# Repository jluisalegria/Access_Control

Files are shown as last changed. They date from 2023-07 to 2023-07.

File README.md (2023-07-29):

# Access control with RFID reader. IoT Contest 2023 RT-Thread.

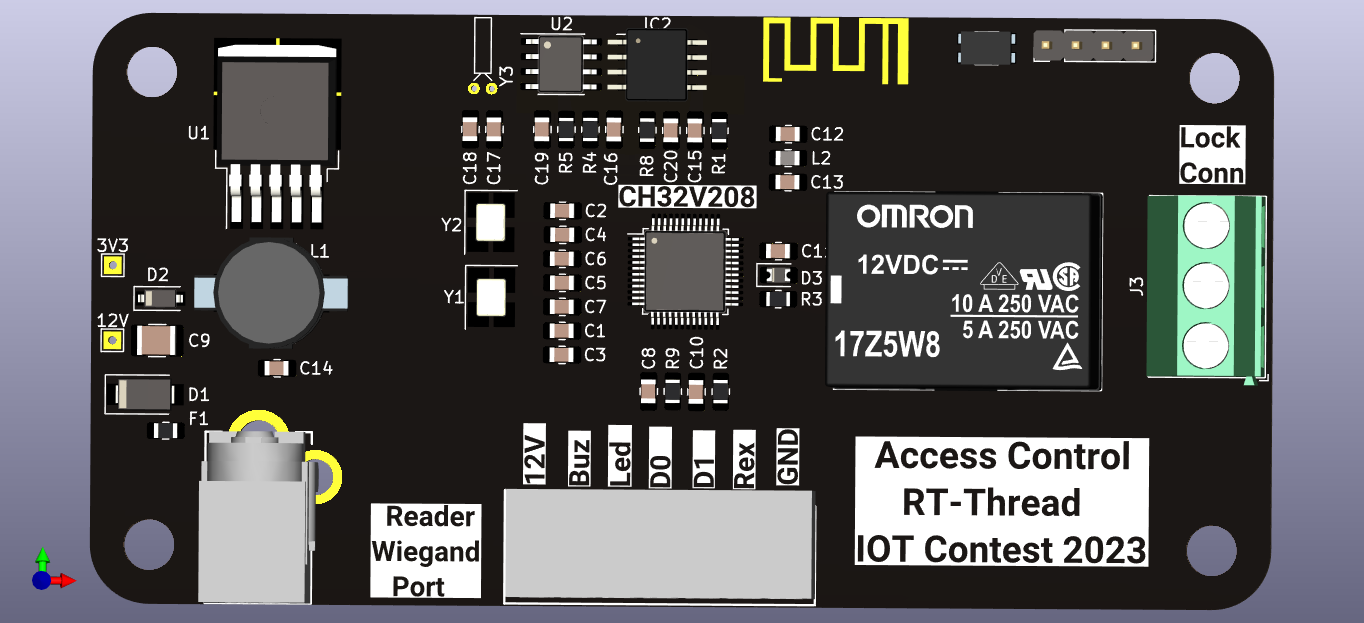
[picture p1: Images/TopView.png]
TOP

# Introduction
I made this project to participate in the IoT contest from RT-Thread.  
[RT-Thread](https://www.rt-thread.io/ "RT-Thread") is a tiny and elegant IoT Operating System.

RT-Thread Features
- Designed for resource-constrained devices, the minimum kernel requires only 1.2KB of RAM and 3 KB of Flash.
- Has rich components and a prosperous and fast growing package ecosystem.
- Elegant code style, easy to use, read and master.
- High Scalability. RT-Thread has high-quality scalable software architecture, loose coupling, modularity, is easy to tailor and expand.
- Supports high-performance applications.
- Supports cross-platform and a wide range of chips.

# Brief
On this project I create my own access control board with RFID wiegand 26 compatible.
There are too many comercial devices, but always the protocolo and software are close, and you have to use the software that the vendor have.
In my case I want to create this access control with the finality to add more functionalityes, for example, automatization of lights AAC control, proyectors, etc. When the people try to access to an area.
The main of this is for using in universities, thet have too many classrooms, in this first version yo can take control of the door, and you can control the light in the classroom using your RFID card. I want to add in a future second version a Led IR, to control more devices, like mini-splits, projectors and TV's.

# Hardware:
* CH32V208RBT6. I select this version because have a LQFP version. More easy to handsolder than the CH32V208WBU6 QFN.  
* RFID reader 125KHz. Modelo: PROID30-BE
* Relay Omron
* Eeprom I2C 2 MBits M24M02-DR M24M02-R
* RTC PCF8523

# Software:
* Code based on RT-Thread
* Own develop software "Sistema de control de acceso SICARFID"

# Wiring the Componets

|Reader  |Dev Board|
|---|---|
|Data 0  | PC9  |
|Data 1  | PC8  |
|Buzzer  | PC6  |
|Led | PC7  |
|GND | GND  |
|+5V | +5V  |

|Relay |Dev Board|
|---|---|
|RLY | PB15 |
|+5V | +5V  |

# TODO:
* Import the BSP from the repository for the WCH boards to make compile the project, with the toolchain RISC-V-GCC-WCH
* EEPROM Library
* RTC Library
* Routing
* Fab PCB

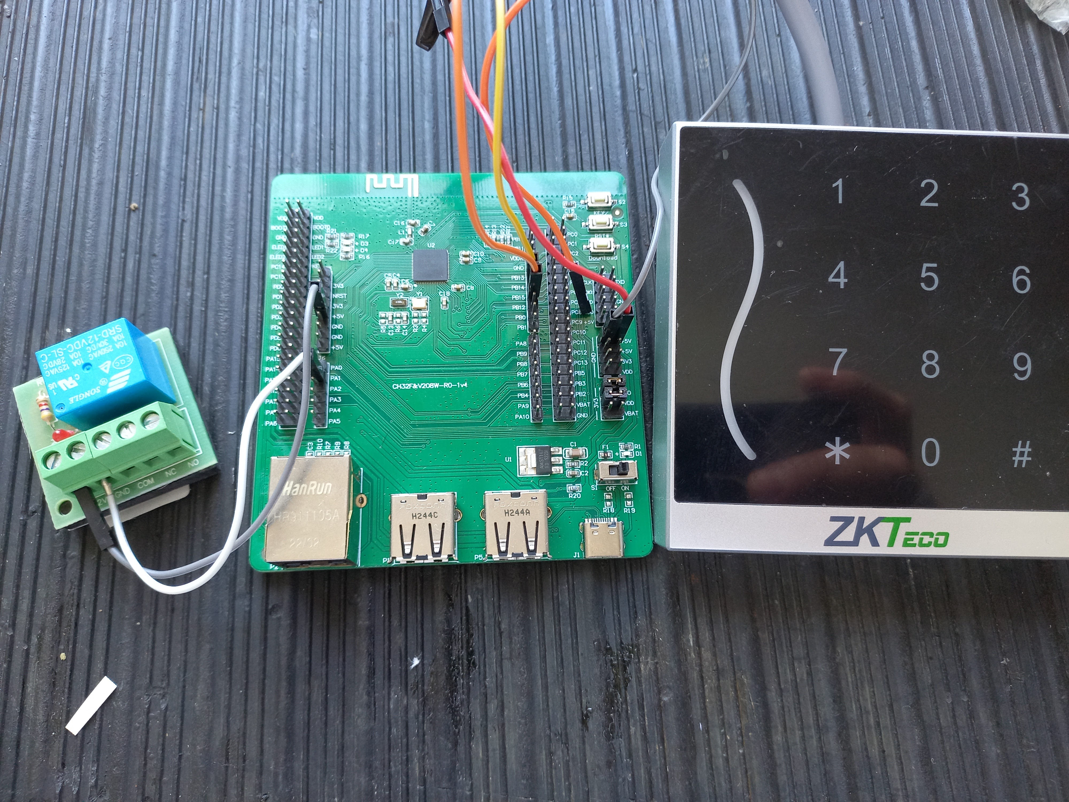
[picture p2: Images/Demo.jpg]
Demo

TOP
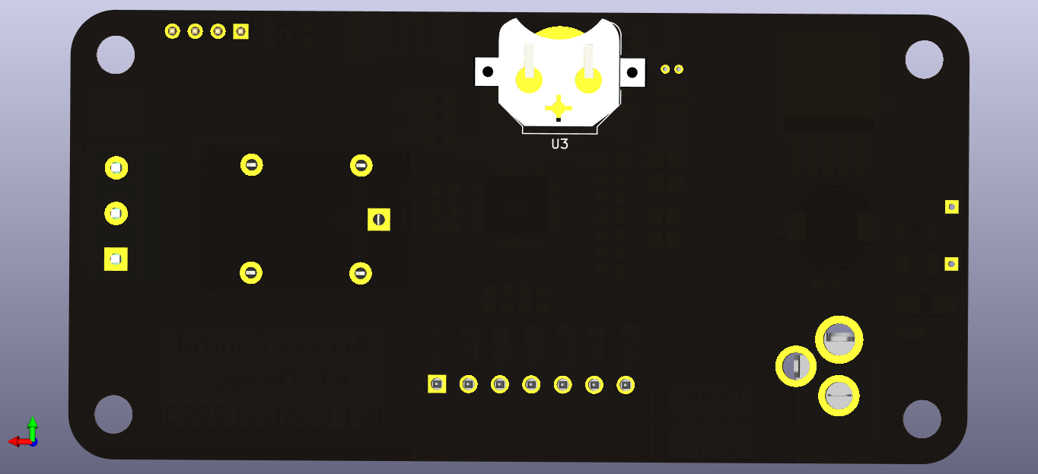
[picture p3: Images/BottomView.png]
BOTTOM

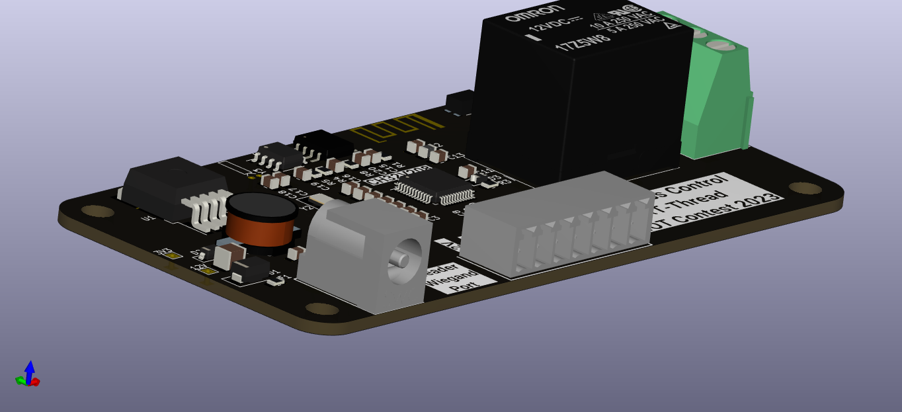
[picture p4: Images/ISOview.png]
ISO

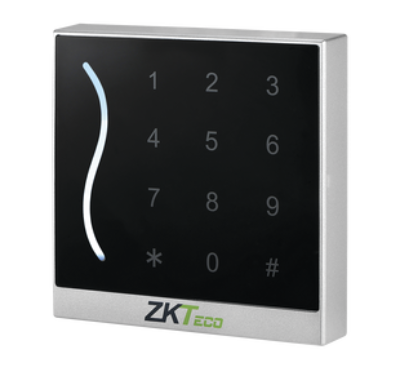
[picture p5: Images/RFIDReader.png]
RFID

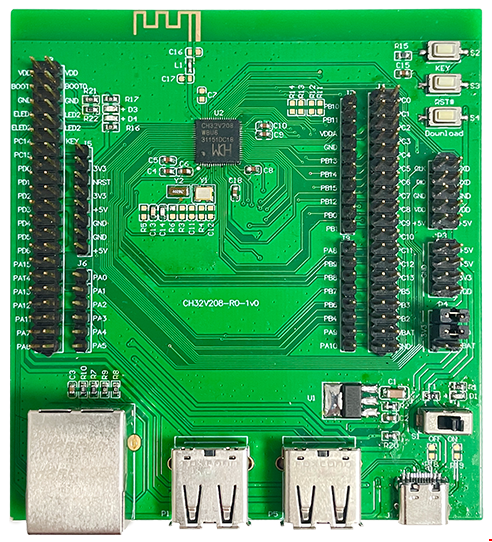
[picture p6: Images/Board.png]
Board


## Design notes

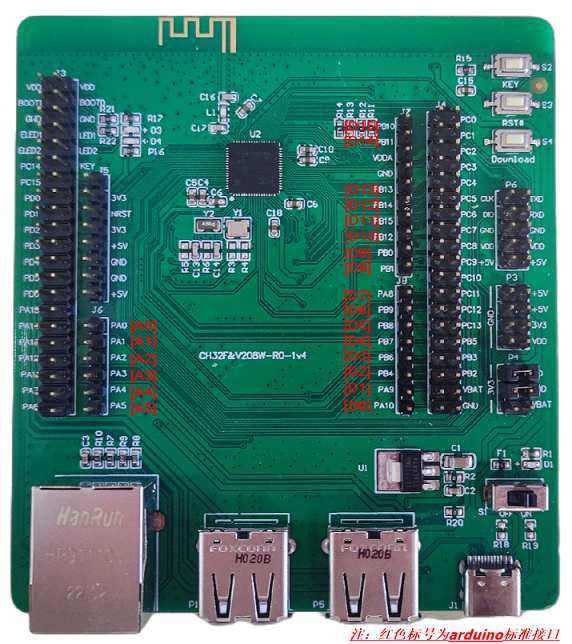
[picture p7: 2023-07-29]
Firmware/Access_Control_IoT_Contest/applications/arduino_pinout/ch32v208w-pinout.png

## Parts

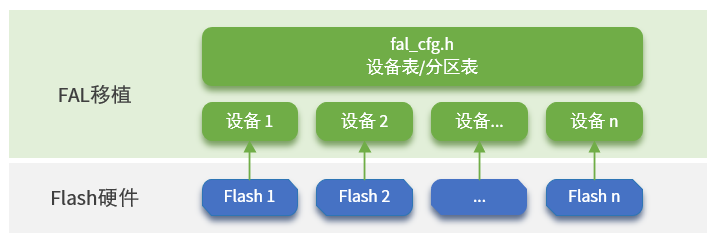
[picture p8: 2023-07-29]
Firmware/Access_Control_IoT_Contest/rt-thread/components/fal/docs/figures/fal-port.png

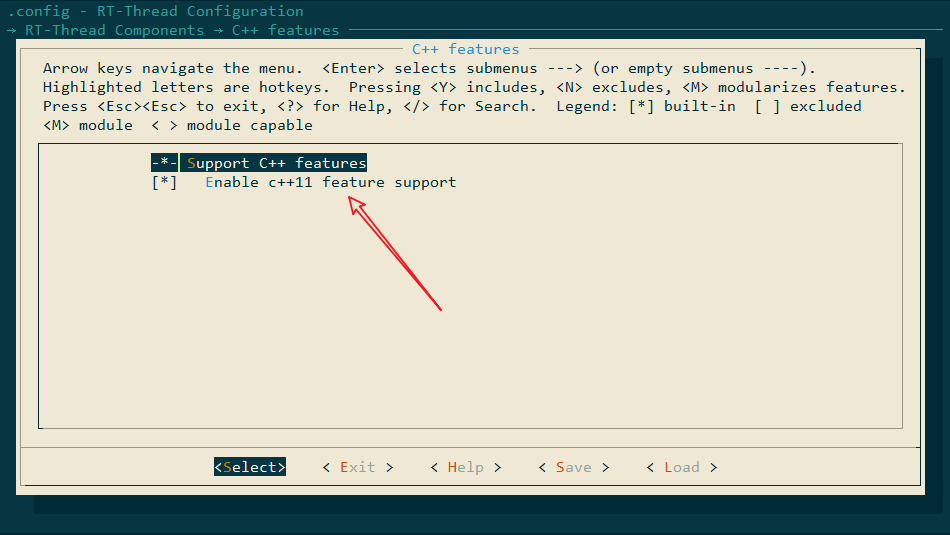
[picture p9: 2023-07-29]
Firmware/Access_Control_IoT_Contest/rt-thread/components/libc/cplusplus/cpp11/figures/Snipaste_2021-09-02_16-00-09.png

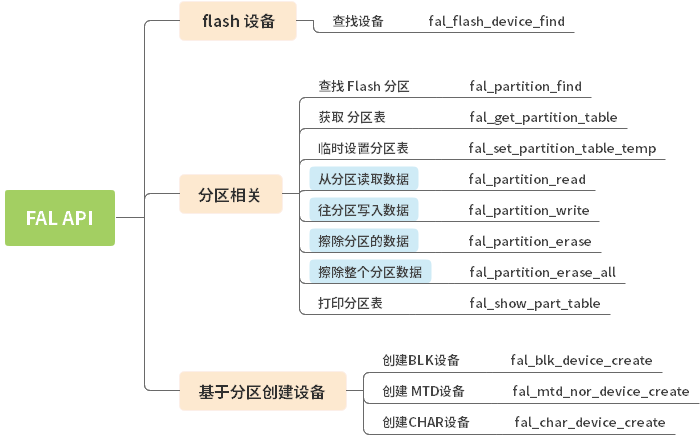
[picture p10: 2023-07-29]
Firmware/Access_Control_IoT_Contest/rt-thread/components/fal/docs/figures/fal-api.png

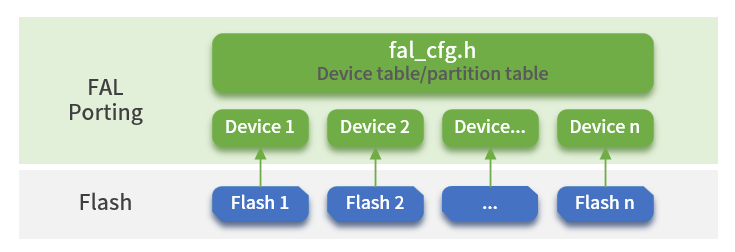
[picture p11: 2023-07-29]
Firmware/Access_Control_IoT_Contest/rt-thread/components/fal/docs/figures/fal-port-en.png

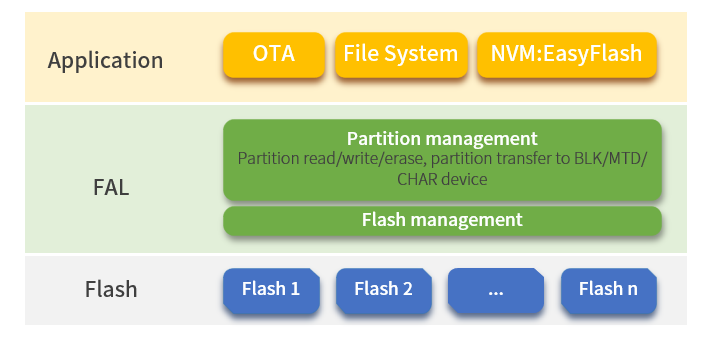
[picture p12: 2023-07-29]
Firmware/Access_Control_IoT_Contest/rt-thread/components/fal/docs/figures/fal_framework-en.png

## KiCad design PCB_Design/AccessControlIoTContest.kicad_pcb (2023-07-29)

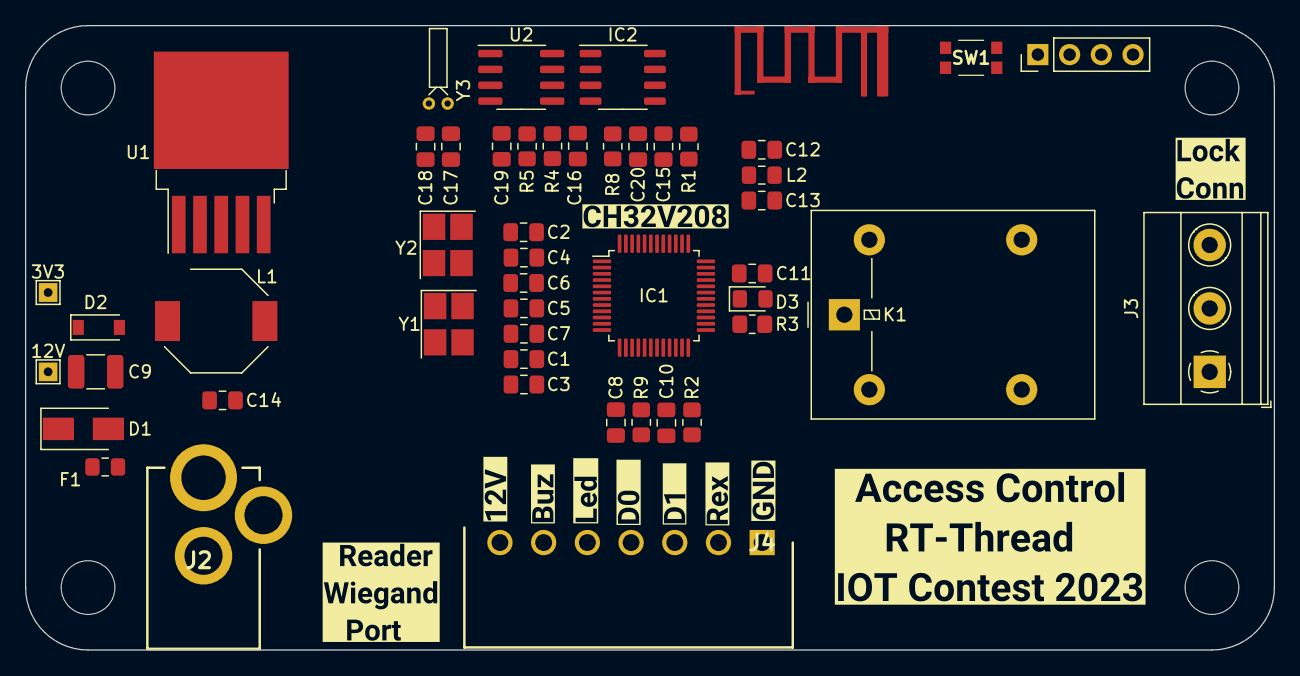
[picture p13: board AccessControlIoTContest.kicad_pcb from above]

Board: 2 copper layers, 100.0 x 50.0 mm, 65 parts (1 on the bottom side), 35 nets, no tracks yet.

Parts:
3V3, 12V: TestPoint; TestPoint_THTPad_1.5x1.5mm_Drill0.7mm
AE1: Antenna; ANT-F-1-2.4G-0.2MM-FPC-WCH
C1, C2, C3, C4, C17, C18: 12pF; C_0805_2012Metric_Pad1.18x1.45mm_HandSolder
C5, C6, C7, C8, C10, C11, C16, C20: 0.1uF; C_0805_2012Metric_Pad1.18x1.45mm_HandSolder
C9: 100uF; C_1210_3225Metric_Pad1.33x2.70mm_HandSolder
C12, C13: 1pF; C_0805_2012Metric_Pad1.18x1.45mm_HandSolder
C14: 100uF; C_0805_2012Metric_Pad1.18x1.45mm_HandSolder
C15: 30pF; C_0805_2012Metric_Pad1.18x1.45mm_HandSolder
C19: 3.3uF; C_0805_2012Metric_Pad1.18x1.45mm_HandSolder
D1: B340A-E3_61T; D_SMA
D2: 1N5817; D_SOD-123
D3: Yellow; D_0805_2012Metric_Pad1.15x1.40mm_HandSolder
F1: 0ZCG0260BF2B; Fuse_0805_2012Metric_Pad1.15x1.40mm_HandSolder
H1, H2, H3, H4: MountingHole; MountingHole_4.3mm_M4
IC1: CH32V208RBT6; CH32V203C8T6_LQFP-48_7x7mm_P0.5mm
IC2: M24M02-DRMN6TP; SO-8_3.9x4.9mm_P1.27mm
J1: Conn_01x04_Male; PinHeader_1x04_P2.54mm_Vertical
J2: RAPC722X
J3: 1715031; TerminalBlock_Phoenix_MKDS-1,5-3-5.08_1x03_P5.08mm_Horizont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
J4: 39502-1007; SHDRRA7W80P0X350_1X7_2590X920X730P
K1: G5LE-1; Relay_SPDT_Omron-G5LE-1
L1: SRU8043-101Y; L_Bourns-SRU8028_8.0x8.0mm
L2: L_Small; L_0805_2012Metric_Pad1.15x1.40mm_HandSolder
R1, R2, R9: 10K; R_0805_2012Metric_Pad1.20x1.40mm_HandSolder
R3, R8: 1K; R_0805_2012Metric_Pad1.20x1.40mm_HandSolder
R4, R5: 4K; R_0805_2012Metric_Pad1.20x1.40mm_HandSolder
SW1: SW_Push; KMR621NGLFS
U1: GL2576-3.3TA5R; TO-263-5_TabPin3
U2: PCF8523T; SOIC-8_3.9x4.9mm_P1.27mm
U3: BAT-HLD-001; BatteryHolder_Keystone_3000_1x12mm
Y1, Y2: 32MHz; Crystal_SMD_SeikoEpson_FA238-4Pin_3.2x2.5mm_HandSoldering
Y3: 32.768KHz; Crystal_DS10_D1.0mm_L4.3mm_Horizontal
kibuzzard-64C431A8: G***; kibuzzard-64C431A8
kibuzzard-64C431B7: G***; kibuzzard-64C431B7
kibuzzard-64C431C2: G***; kibuzzard-64C431C2
kibuzzard-64C431CD: G***; kibuzzard-64C431CD
kibuzzard-64C431DA: G***; kibuzzard-64C431DA
kibuzzard-64C431EA: G***; kibuzzard-64C431EA
kibuzzard-64C4306F: G***; kibuzzard-64C4306F
kibuzzard-64C4325D: G***; kibuzzard-64C4325D
kibuzzard-64C43168: G***; kibuzzard-64C43168
kibuzzard-64C43228: G***; kibuzzard-64C43228
kibuzzard-64C43248: G***; kibuzzard-64C43248

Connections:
+3.3V: C8.1, C10.2, IC1.19 (VDD_VIO_4), IC1.32 (VDD_VIO_1), J1.4, SW1.2
+3V3: 3V3.1, C14.1, C16.1, C20.1, IC2.3 (E2), IC2.8 (VCC), K1.5, L1.2, R3.1, R4.1, R5.1, R8.1, R9.1, U1.4 (FB)
+12V: 12V.1, C9.1, D1.1, F1.2, J4.7, U1.1 (VIN)
/COM1: J3.2, K1.1
/NC1: J3.3, K1.4
/NO1: J3.1, K1.3
/OUT: D2.1 (K), L1.1, U1.2 (OUT)
Buzzer: IC1.37 (PC6/RXP), J4.6
DATA0: IC1.40 (PC9/TXN), J4.4
DATA1: IC1.39 (PC8/TXP), J4.3
GND: C1.1, C2.1, C3.1, C4.1, C5.1, C6.1, C7.1, C8.2, C9.2, C10.1, C11.2, C12.1, C13.1, C14.2, C15.2, C16.2, C17.2, C18.2, C19.1, C20.2, D1.2, D2.2 (A), IC1.5 (VSSA), IC1.18 (VSS_4), IC1.31 (VSS_1), IC2.1 (DU_1), IC2.2 (DU_2), IC2.4 (VSS), IC2.7 (~WC), J1.3, J2.1, J2.2, J4.1, R1.1, R2.2, U1.3 (GND), U1.5 (~ON/OFF), U2.4 (VSS), Y1.2, Y1.4, Y2.2, Y2.4
Led: IC1.38 (PC7/RXN), J4.5
unnamed: AE1.1 (A), C13.2, L2.2
unnamed: C5.2, IC1.8 (NRST)
unnamed: C6.2, IC1.1 (VBAT)
unnamed: C7.2, IC1.14 (PA0/WKUP/ADC0)
unnamed: C11.1, IC1.47 (VINTA)
unnamed: C12.2, IC1.48 (ANT), L2.1
unnamed: C17.1, U2.2 (OSCO), Y3.1
unnamed: C18.1, U2.1 (OSCI), Y3.2
unnamed: C19.2, R8.2, U2.8 (VDD)
unnamed: D3.2 (A), R3.2
unnamed: R1.2, SW1.1
unnamed: IC1.28 (PB2/BOOT1), R2.1
unnamed: U2.3 (VBAT), U3.1, U3.2
OSC32IN: C2.2, IC1.3 (PC14/OSC32IN), Y2.1
OSC32OUT: C4.2, IC1.4 (PC15/OSC32OUT), Y2.3
OSC_IN: C1.2, IC1.6 (OSC_IN), Y1.1
OSC_OUT: C3.2, IC1.7 (OSC_OUT), Y1.3
REX1: J4.2, R9.2
Relay: D3.1 (K), IC1.36 (PB15), K1.2
SCL: IC1.41 (PA8), IC2.6 (SCL), R4.2, U2.6 (SCL)
SDA: C15.1, IC1.42 (PA9), IC2.5 (SDA), R5.2, U2.5 (SDA)
SWDIO: IC1.46 (PA13/SWDIO), J1.1
VCC: F1.1, J2.3

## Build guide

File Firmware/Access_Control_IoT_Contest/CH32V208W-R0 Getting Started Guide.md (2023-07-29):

# CH32V208W-R0 User Guide

**English** | [中文](./CH32V208W-R0上手指南.md)

The CH32V208W-R0 supports RT-Studio projects, and this tutorial gives an example of development instructions for the RT-Studio environment.

## 1 Preparation Stage

- Pull the github repository for rt-thread locally, [link address](https://github.com/RT-Thread/rt-thread).
- Download and install RT-Thread Studio, [link to address](https://www.rt-thread.org/studio.html).
- Prepare the ESP8266 module.

## 2 BSP Start Stage

### 2.1 Click on the file and select the import option.

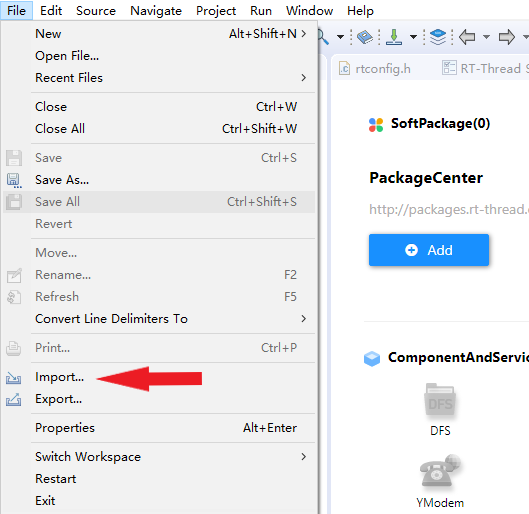
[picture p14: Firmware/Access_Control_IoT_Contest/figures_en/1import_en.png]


### 2.2 Select to import RT-Thread BSP into the workspace

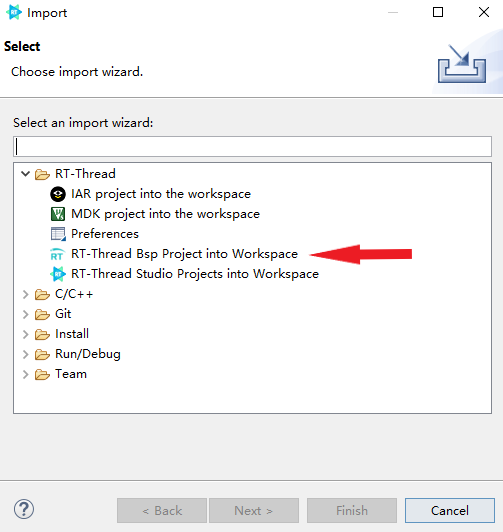
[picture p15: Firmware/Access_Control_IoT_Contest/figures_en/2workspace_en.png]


### 2.3 Fill in the project information according to the example

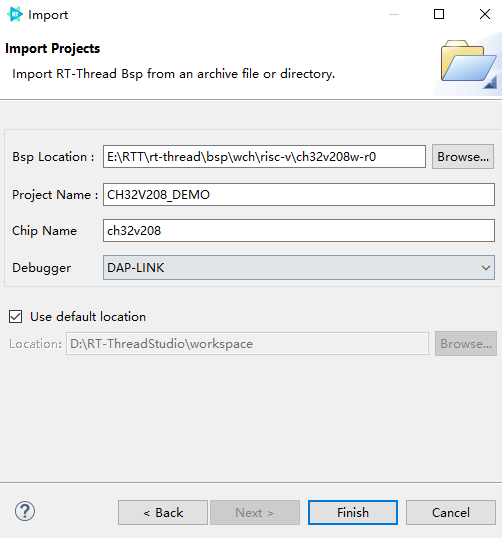
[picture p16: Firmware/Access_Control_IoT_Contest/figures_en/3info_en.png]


### 2.4 Configuration Engineering

After importing the project, there is a reference document readme in the root directory of the project, first of all, follow the readme.md for basic configuration

In order to reduce the memory increase caused by the standard library added during linking, we can choose to use the relatively small memory consumption of newlib, as follows：

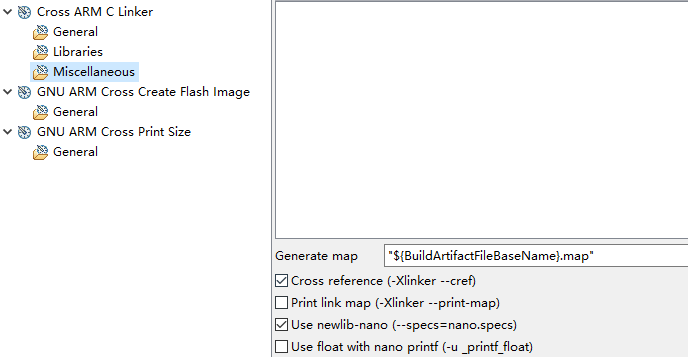
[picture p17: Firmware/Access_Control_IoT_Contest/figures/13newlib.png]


### 2.5 Compiling the project

Click on the compile option:



Compile result:

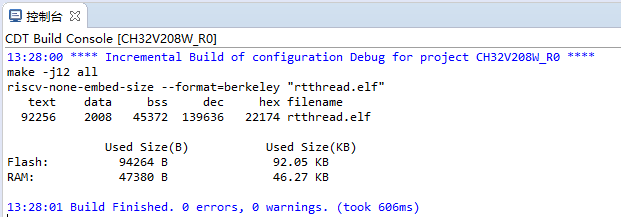
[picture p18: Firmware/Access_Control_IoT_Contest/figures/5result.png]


The project compiles and passes, and thus the preparation phase is completed.

## 3 Configuring the BSP driver with RT-Studio

Each BSP of RT-Thread has been configured with several on-chip peripheral drivers and onboard peripheral drivers by default, use RT-Studio to turn on the corresponding switches directly and configure the corresponding parameters according to the usage environment to use. Due to the multiplexing function of each pin, not all on-chip peripheral drivers and onboard peripheral drivers can be used at the same time, so you need to combine them with the schematic to enable the corresponding peripheral drivers.

RT-Thread has a number of software packages, which can be added to the project by turning on the corresponding package switch using RT-Studio.

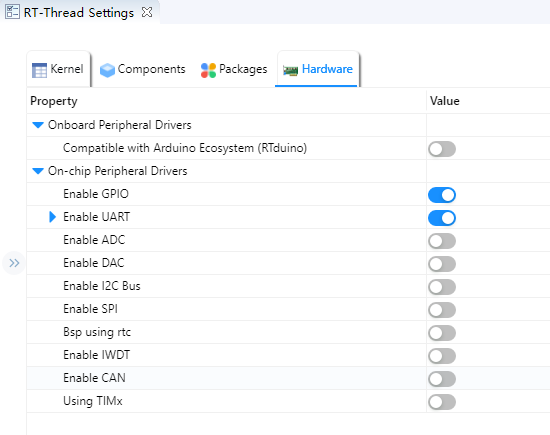
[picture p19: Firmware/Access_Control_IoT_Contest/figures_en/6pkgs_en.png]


## 4 Networking with ESP8266 modules

The ESP8266 is a cost-effective, highly integrated Wi-Fi MCU for IoT applications, and can also be used as a standalone WIFI module with the following physical diagram. ESP8266 modules usually support [AT](https://www.rt-thread.org/document/site/#/rt-thread-version/rt-thread-standard/programming-manual/at/at), RT-Thread provides an abstraction layer for these modules that support AT instructions, and this summary will use the AT group to communicate with ESP8266 and connect WIFI.

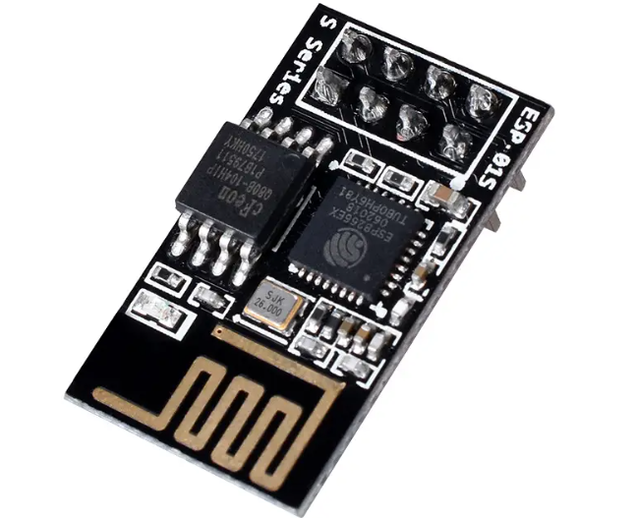
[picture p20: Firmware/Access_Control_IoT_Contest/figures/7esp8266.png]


### 4.1 Configuring Onboard UART Peripherals

Using the AT component to communicate with the ESP8266 module using serial communication, so we need to enable one more serial port, here we use UART2, the serial driver is already supported by default, we just need to open it in RT-Studio when we use it, as follows:

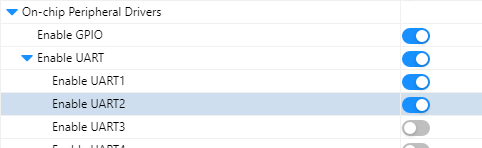
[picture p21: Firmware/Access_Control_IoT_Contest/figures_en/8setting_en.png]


After turning on the option, `ctrl + s` saves the settings and serial port 2 is initialized.

### 4.2 Configuring AT components with RT-Studio

Click on the RT-Thread Settings option on the left, the configuration menu on the right pops up, type AT in the search field, select `AT device` and enable the AT device: 

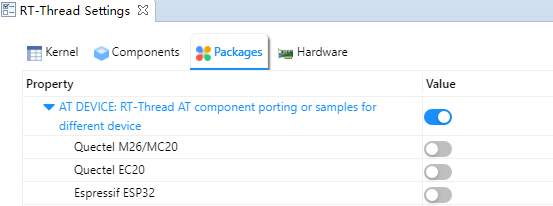
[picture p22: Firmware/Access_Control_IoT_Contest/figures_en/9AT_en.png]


Select the ESP8266 and configure the appropriate parameters, as shown in the example below.

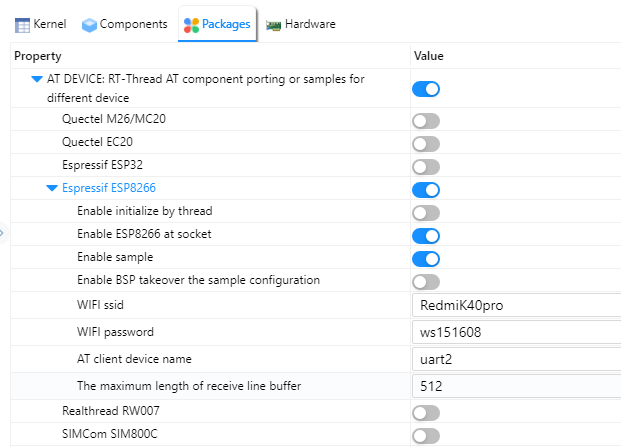
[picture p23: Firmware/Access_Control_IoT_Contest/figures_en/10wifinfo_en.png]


### 4.3 ESP8266 module connection

Connect the `PA2` pin on the board to the `RX` pin of the module, connect the `PA3` pin to the `TX` pin of the module, and power the module using the power supply pinout from the development board.

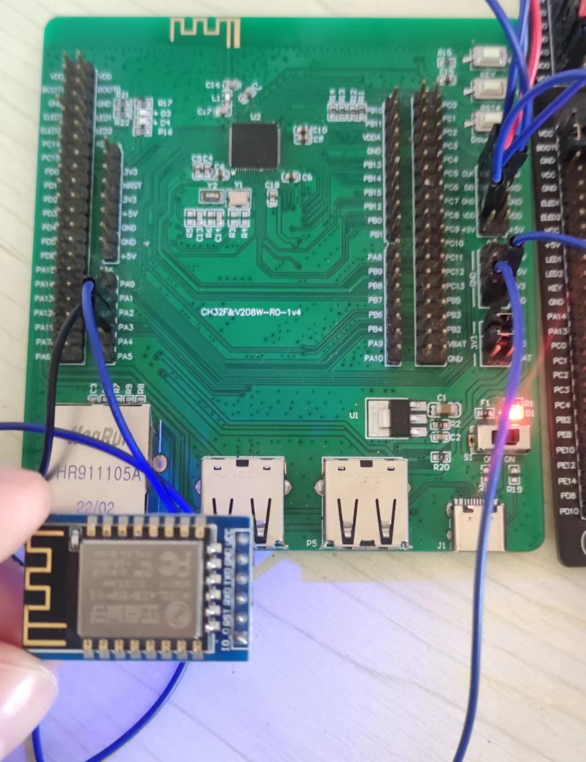
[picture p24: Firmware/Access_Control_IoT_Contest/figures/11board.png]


### 4.4 Enabling kernel debugging.

For a more intuitive understanding of the component initialization process, we can enable the kernel debugging feature to observe it (you can turn it off when not needed) by doing the following:

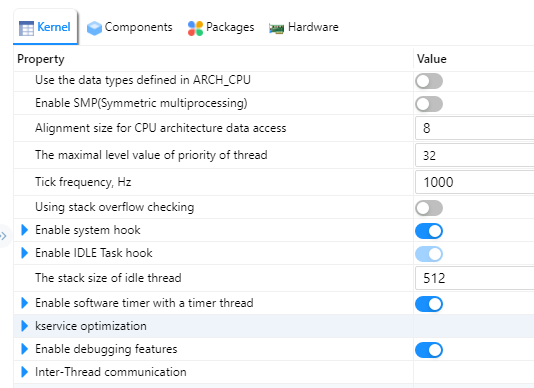
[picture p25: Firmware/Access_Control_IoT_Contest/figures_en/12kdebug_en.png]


Recompile and burn the firmware, the shell output is as follows:

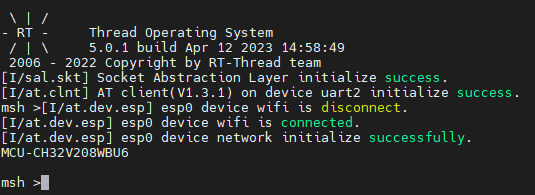
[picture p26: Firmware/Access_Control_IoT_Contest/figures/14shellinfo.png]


### 4.5 wifi networking test

My door has configured the WIFI ID and password when using AT, enter the `ping www.baidu.com` command in the shell to test the WIFI connection.

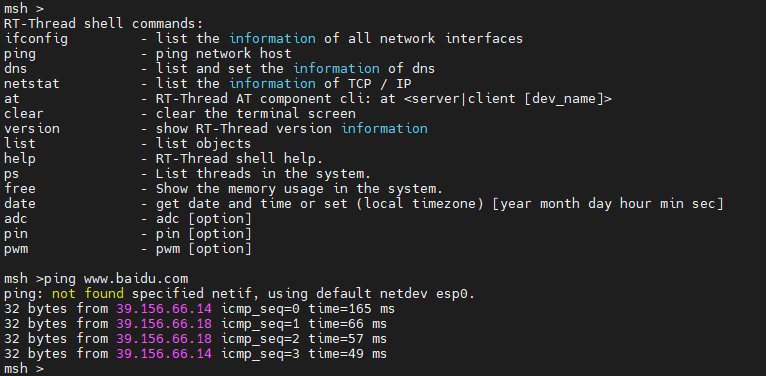
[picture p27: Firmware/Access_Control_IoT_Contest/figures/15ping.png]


Output similar content, the ESP8266 module is connected successfully!

### 5 RTduino components

[RTduino](https://github.com/Yaochenger/RTduino) is the Arduino eco-compatible layer of the RT-Thread real-time operating system, and is a sub-community of the [RT-Thread community](https://github.com/RT-Thread/rt- thread), the downstream project of the Arduino open source project, aims to be compatible with the Arduino community ecology to enrich the RT-Thread community package ecology (such as thousands of different Arduino libraries, as well as the excellent open source projects of the Arduino community), and to reduce the learning threshold of the RT-Thread operating system and the chips compatible with RT-Thread. and RT-Thread-adapted chips.

#### 5.1 Configuring RTduino

Turn on the RTduino option in the onboard device driver.



After turning on the option, `ctrl + s` saves the settings and the RTduino package can be added to the project.

#### 5.2 Using RTduino

In `arduino_main.cpp` you will see the familiar `void setup(void)` and `void loop(void)`, so we can use the BSP here like the official arduino board, the sample code is as follows:

```c++
#include <Arduino.h>

void setup(void)
 {
     /* put your setup code here, to run once: */
    pinMode(LED_BUILTIN, OUTPUT).
 }

void loop(void)
{
    /* put your main code here, to run repeatedly: */
    digitalWrite(LED_BUILTIN, !digitalRead(LED_BUILTIN)).
    delay(100).
}

```

 By default, the project performs a blinking LED function. ch32v208w-r0, the default on-board LED is not directly connected to the pin, the user needs to manually connect the LED to the control pin using a duplex cable, the phenomenon is shown below:

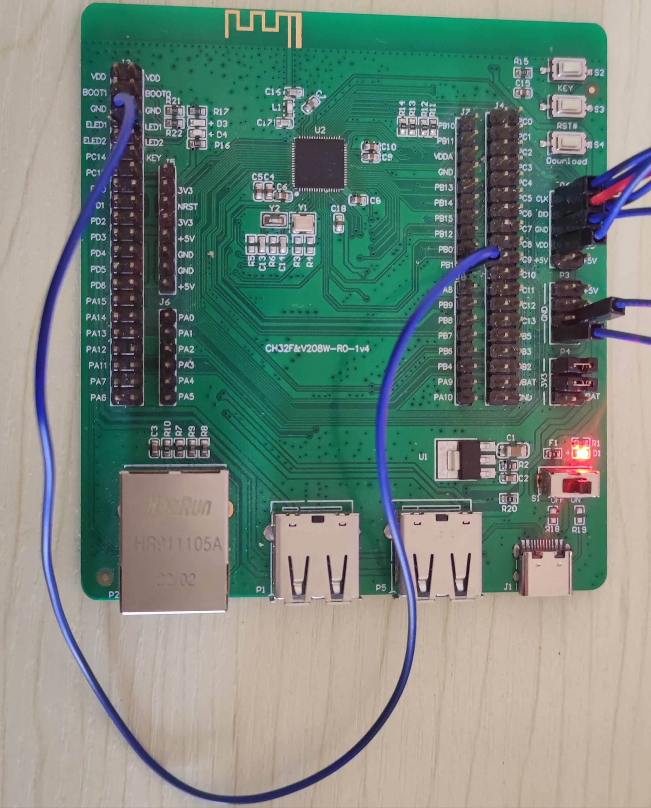
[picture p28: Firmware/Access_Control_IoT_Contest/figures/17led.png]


So the basic environment of ch32v208w-r0 is built and tested!

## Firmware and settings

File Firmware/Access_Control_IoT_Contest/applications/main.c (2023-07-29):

/*
 * Copyright (c) 2006-2023, RT-Thread Development Team
 *
 * SPDX-License-Identifier: Apache-2.0
 *
 * Change Logs:
 * Date           Author       Notes
 * 2022-11-03     WangShun       first version
 */

#include "ch32v20x.h"
#include <rtthread.h>
#include <rthw.h>
#include "drivers/pin.h"
#include <board.h>

#define LED0 rt_pin_get("PA.0")

int main(void)
{
    rt_pin_mode(LED0,PIN_MODE_OUTPUT);
    rt_kprintf("MCU-CH32V208WBU6\r\n");
    while(1)
    {
        rt_pin_write(LED0, PIN_HIGH);
        rt_thread_mdelay(500);
        rt_pin_write(LED0, PIN_LOW);
        rt_thread_mdelay(500);
    }
}
